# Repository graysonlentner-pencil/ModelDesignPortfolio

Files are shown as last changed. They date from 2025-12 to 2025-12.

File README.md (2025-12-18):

Model & Design Project:
Automated Snow Machine - Model & Design  |  Spring Semester, 2025.
Collaborated with a team to construct a scaled-down version of a snow machine that was able to pivot the nozzle, allowing for a wider range and thus reducing the number of machines to cover a hill. 
Developed a 3D model (Designed in OnShape) of a miniature air compressor powered by a stepper motor, as well as a pinch valve controlled by a servo motor.
Featured as a finalist in the 2025 MTU Design Expo.

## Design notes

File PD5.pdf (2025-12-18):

L36 _ 05
Megan Antczak, Clare Kowalczyk, Grayson Lentner, Noah Walters

PD5 - FMEA Memo

Executive Statement/Introduction

In this memo, we discuss the implication of FMEA, or Failure Modes and Effects Analysis, in our current project, an autonomous snowmaker. This analysis will allow us to effectively detect errors and failures in our design, and minimize them to the fullest extent possible without reducing the effectiveness or functionality of the device. This stage of development is essential for the customer, as major safety hazards and defects to the user are caught. New changes to the existing design are then made to eliminate these failures to the best of the designer’s ability.

Background

Our product is an autonomous snowmaker. The objective of our product is to improve skiing conditions for the large population of skiers, specifically in the Midwest region. Our product will autonomously detect ideal snowmaking conditions using temperature and humidity sensors and the necessity to make new snow. If a need for more snow is detected, our product will create new snow through a device with a pressurized pump with a mist nozzle. This design will evenly distribute uniform snow in hazardous areas. This innovation will greatly improve the consistency of slopes. Therefore, skiers' safety, enjoyment, and overall experience will be substantially enhanced.
This product will bring attention to the importance of maintaining ski hills for recreation and sport. In the upper peninsula last year several popular ski hills had to close very early due to the abnormal winter. With this product, the resorts could extend their season bringing more tourism and innovation to the area.

Methodology

Our procedure for the FMEA analysis is as follows:

1. Description of parts and their modes of failure - Every significant component of our system, including but not limited to the pump, nozzle, and fan is identified. Most failure modes are identified and connected to their corresponding parts.
2. Symptoms, Effects, and Significance Rating - The symptoms of failures are identified along with the possible effects and damages they may have on the customer. The symptoms and effects are then used to conjure a Significance Rating from 1 to 10 based on how severe the failure may be to the customer, with 10 being the most severe.

### 3. Probability of Occurrence Rating - Notes are produced to determine how likely

the failure mode is to occur, and then a probability rating from 1 to 10, with 10 being the most likely, is determined based on these notes.

### 4. Detectability Rating - Notes about how a failure mode may be detected before it

occurs are taken, and then are used to determine a detectability rating from 1 to 10, 10 being the least detectable.

### 5. Risk Priority Value - Risk priority values are calculated by multiplying the

significance rating, probability rating, and detectability rating together. The risk priority value is then used to determine which failure modes require the most attention.

Results and Discussion

Through our discussion of each hazard and the completion of the FMEA analysis, we identified 8 different components of our design to revise. These include the water pump, mist nozzle, tubing, DC motor/fan, servo, servo value, wiring, and temperature and humidity sensor. We went over multiple different fail mechanisms for each of the components through research into common problems as well as thinking through environmental conditions or basic human errors that might occur.

Parts, Concerns, & Solutions

### 1. Water Pump: (clogged, internal friction, not enough power/pressure supplied)

Solutions: Create a protective structure over the inlet, apply lubricant to areas of friction, and modify the stepper motor to supply greater torque.
– Average Risk Priority Number: 58.7
2. Mist Nozzle: (uneven water distribution, unsuitable mist power, clogged, freezes over, breaks from failure)
Solutions: use references for nozzle design, test design with the right pressure and environmental conditions, calibrate to apply the right amount of pressure, and use durable material and design aspects.
– Average Risk Priority Number: 162.5

### 3. Tubing: (leaks, freezes over)

Solutions: use extra adhesive or connective material (tape), and heat/insulate the water supply to keep it from freezing
– Average Risk Priority Number: 224

### 4. DC Motor / Fan: (not enough air current to propel mist)

Solutions: determine the right current and proper mist size before in a test environment
– Average Risk Priority Number: 60

### 5. Servo: (motor fails)

Solutions: intentional placement to minimize failure of moving marts – Average Risk Priority Number: 8

### 6. Servo Value: (seal is not sufficient)

Solutions: rubber material to create a seal
– Average Risk Priority Number: 80

### 7. Wiring: (not secured/comes loose, short circuits)

Solutions: if they come undone they will be detected through electronics not operating, and can be fixed manually after that, prevention includes checking all connections before the final assembly
– Average Risk Priority Number: 18

### 8. Temperature & Humidity: (correct conditions are not detected, doesn’t work)

Solutions: testing before implementation into the device.
– Average Risk Priority Number: 36

Many of the hazards resulted in unsafe conditions for users of the ski hills, thus our rating for failure severity was based on how dangerous it was to the public. In cases where the water was distributed in heavy amounts, the snow would not form in the process of the device. This would create more ice patches on the ski hills and make the slope very dangerous for any of the people using it that day. Best case scenario, the ski hill would have to close down for the day and lose profit. Other hazards resulted in the device failing to work, so those were rated less severe due to no possibility of human casualty.

We chose the mist nozzle and the tubing as our top hazards because almost all of their failure symptoms had consequences involving injury. Both also had a high chance of happening based on how likely it was that they could freeze or break under temperature-induced brittleness. For the mist nozzle we decided to test our 3D printed nozzle before implementation into the design as well as testing it in cold conditions to test whether it would freeze over or fracture. For the tubing, we discussed implementing an insulation system or water heater to keep the water supply from freezing. We also discussed adding extra reinforcement to the joints of the tubing to reduce fractures and leaks.

These changes will reduce the occurrences of such failures and keep extra water from being distributed over the hill. This will result in safer ski hill conditions overall and reduce the impact of such failures on the community.

Conclusion

We have considered many failure modes in our device including frozen water in tubing to reduce hazards that may be brought about by the device. These failure modes were detected via FMEA and included but were not limited to the uneven distribution of water, and torque failures within the motors of the device. Several precautions have been taken to minimize these failures as well as their effects, ensuring the customer will be satisfied with their use of the device. These Precautions include installing insulation within certain parts of the device to prevent freezing, as well as modifying some motors to withstand a higher amount of torque. In total, significant errors and failures of the device are being taken into account and will be minimized in the interest of the user.

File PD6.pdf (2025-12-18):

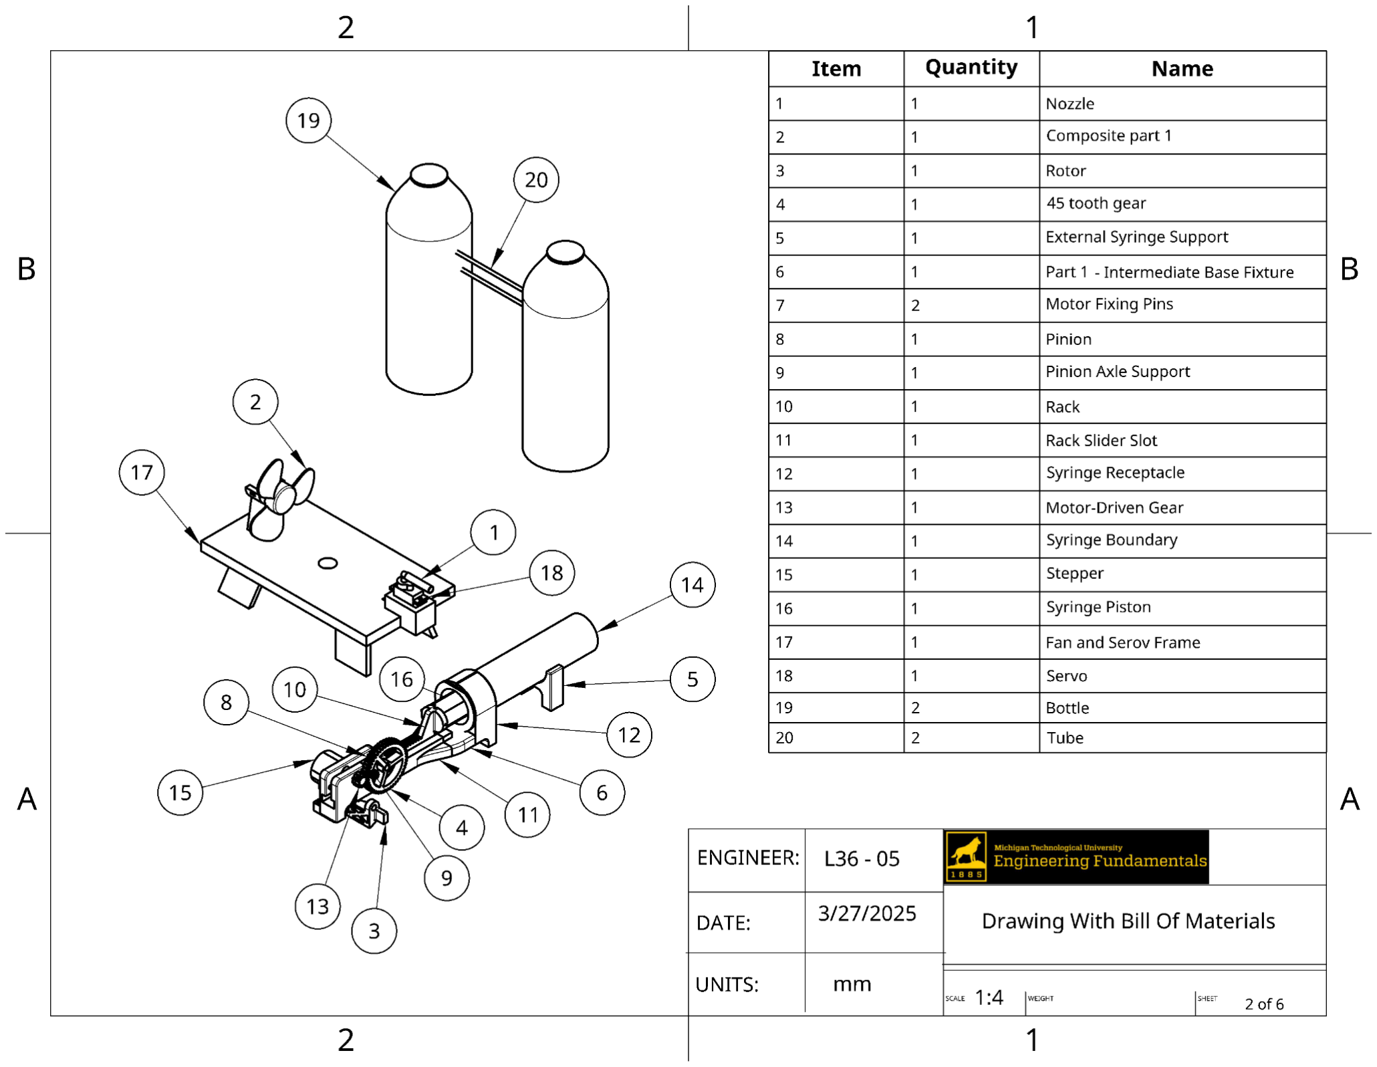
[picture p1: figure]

Introduction

For our project, we are designing an autonomous snow machine. The desired intent of our machine is to create more ideal skiing conditions, as well as make the jobs of the workers easier by not making them scale the ski hill to adjust the machine. The 3D model will play a significant role in helping us visualize what we want our machine to look like when it is fully built. It also allows us to create each individual part to the scale that we need them to be, making it possible to 3D print them.

Progress

Over the weekend, we assigned each team member to design on Onshape some of the different parts that need to be 3D printed. We have each made progress on our assigned parts and some parts have been completed, while others still have a little bit left to do. Grayson has taken the task of creating our pump, which is the most complex and intricate piece we will be 3D printing. Megan has completed the frame for the micro servo and the DC motor. Clare has completed the mist nozzle. Noah made the fan. Everyone has taken responsibility for different complex parts and has excelled. Overall, we are still deciding who needs to do some of the other minor parts on OnShape but we are rather close to being able to print everything.

Challenges

Our team encountered many challenges in the modeling and drawing process. A big struggle was communication after we divided up all the parts. Each person had to work individually but there were still strict guidelines and restrictions that needed to be followed to ensure that our device would run smoothly. Our team had to maintain very effective communication to execute unity for this assembly. Some forms of this communication included drawings on whiteboards, comments on parts, and repeating dimensions multiple times.
It was also challenging to finalize the design of this model. Up until this point, our project was very conceptual and did not have a concrete vision. This project deliverable forced us to begin to bring our ideas to life. Some of the drafting did not go very smoothly but as a team, we worked it out ensuring everyone’s ideas were heard and accounted for. The difficulties and challenges we faced were beneficial and necessary for the production of this project.

Next Steps

The next step of our project includes going to the Fab Lab. Here, we will 3D print many aspects of our project. Such parts include the nozzle, the fan and servo frame, fan blades, and many parts for the pump. After completion of the 3D printing we will thoroughly inspect products to make sure they are up to par and redesign and reprint as needed. After the perfection of our parts, we will put our assembly together. With our project all put together, testing will commence to find any possible flaws with our design. As seen in our FMEA table, each part has its own major or minor potential breaking points. After we have worked out all the flaws, we will have a working machine ready for the final test.

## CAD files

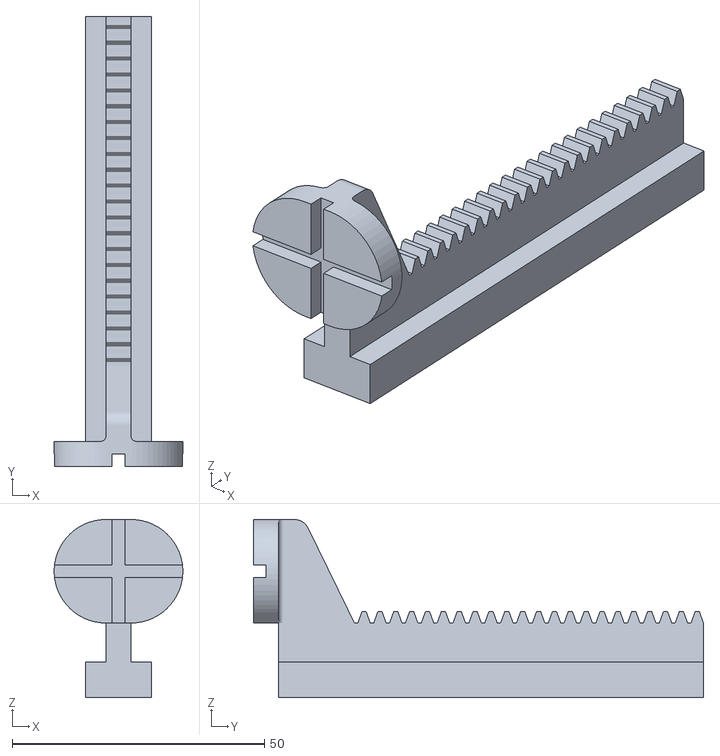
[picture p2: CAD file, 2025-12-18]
Rack.stl
25.5 x 89.1 x 35.2

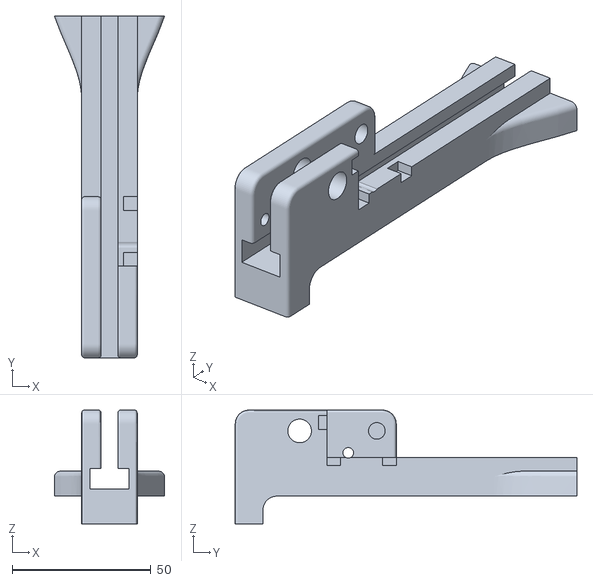
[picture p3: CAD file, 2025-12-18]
Rack slider slot.stl
39.6 x 123.0 x 41.0

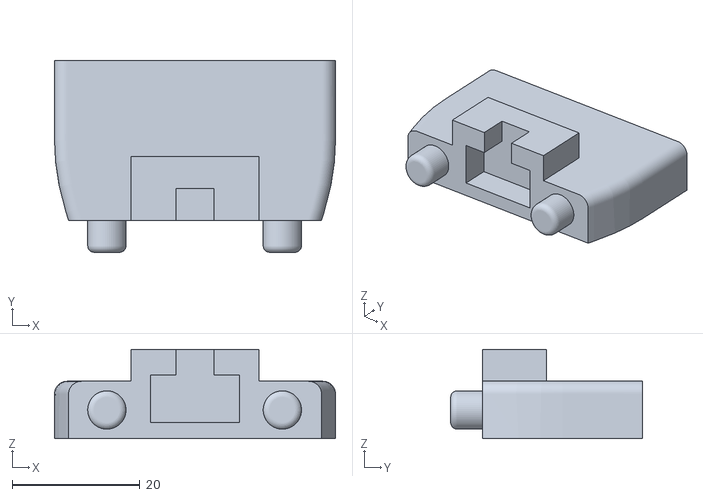
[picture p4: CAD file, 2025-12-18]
Intermediate Base Fixture.stl
44.0 x 30.0 x 14.0

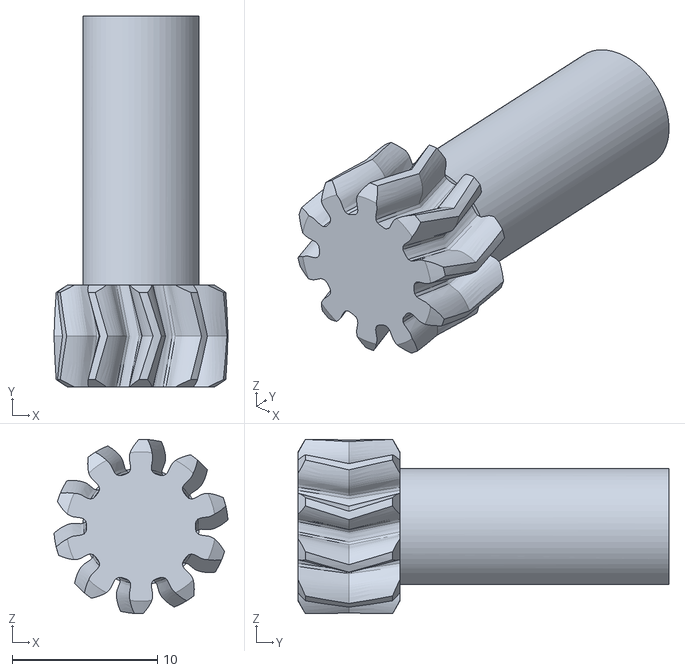
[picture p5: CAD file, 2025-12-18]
Motor-Driven Gear - Motor-Driven Gear.stl
12.0 x 25.5 x 12.0

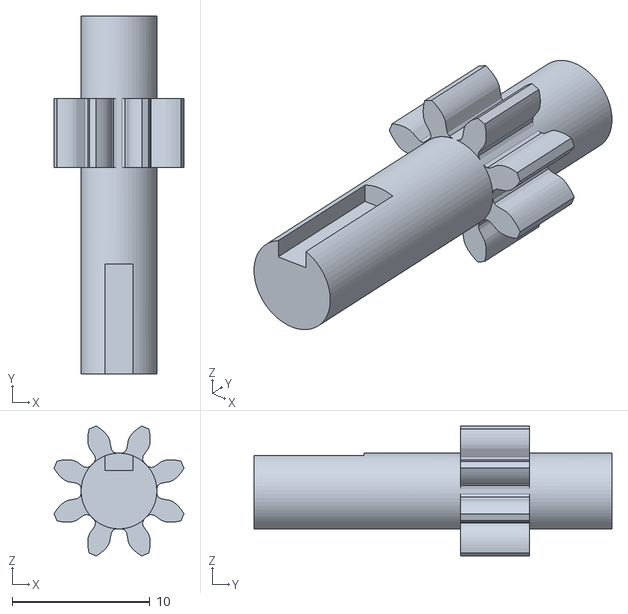
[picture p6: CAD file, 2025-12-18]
Pinion.stl
9.43 x 26.0 x 9.43

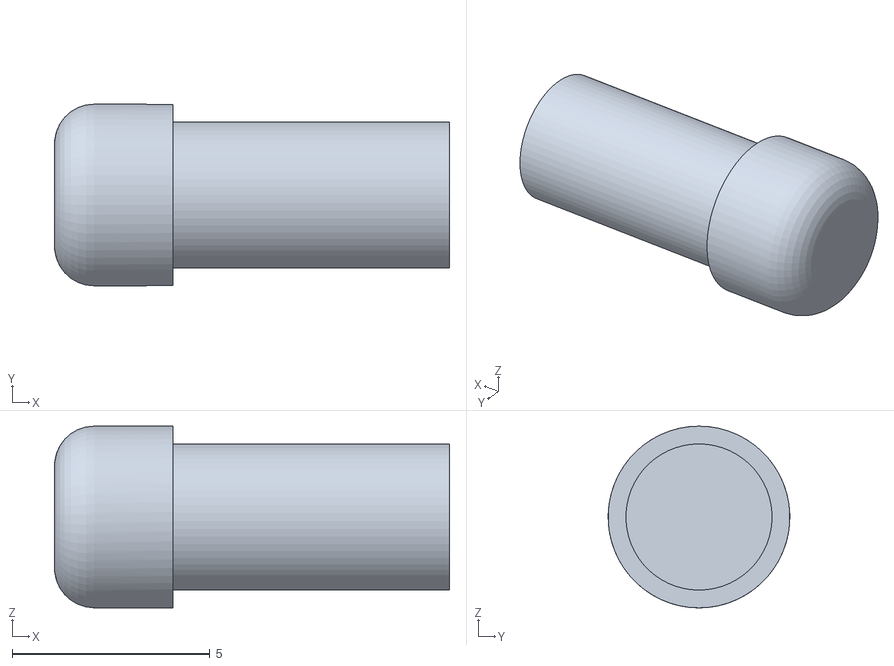
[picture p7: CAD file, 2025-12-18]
Motor fixing pins.stl
10.0 x 4.60 x 4.60

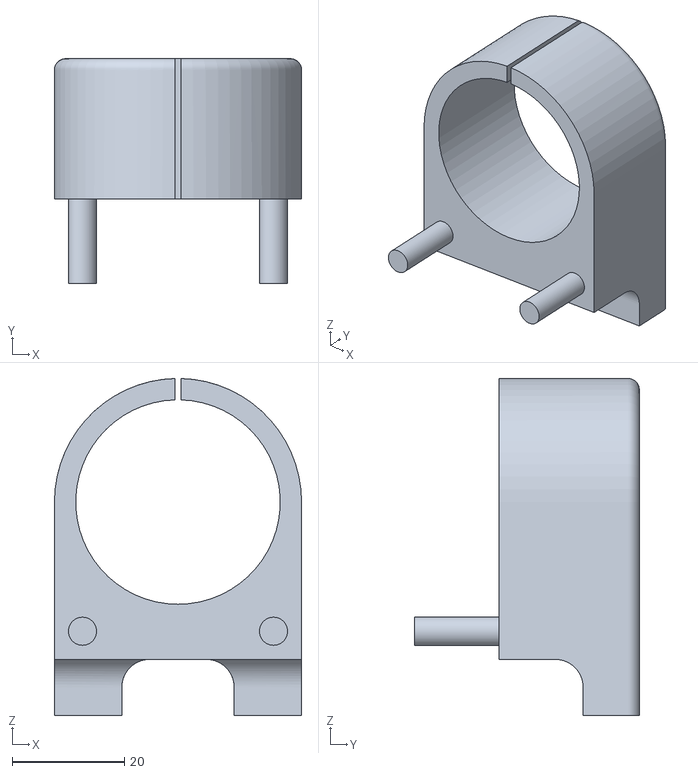
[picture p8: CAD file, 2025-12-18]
Syrnge receptacle.stl
44.0 x 40.0 x 60.0

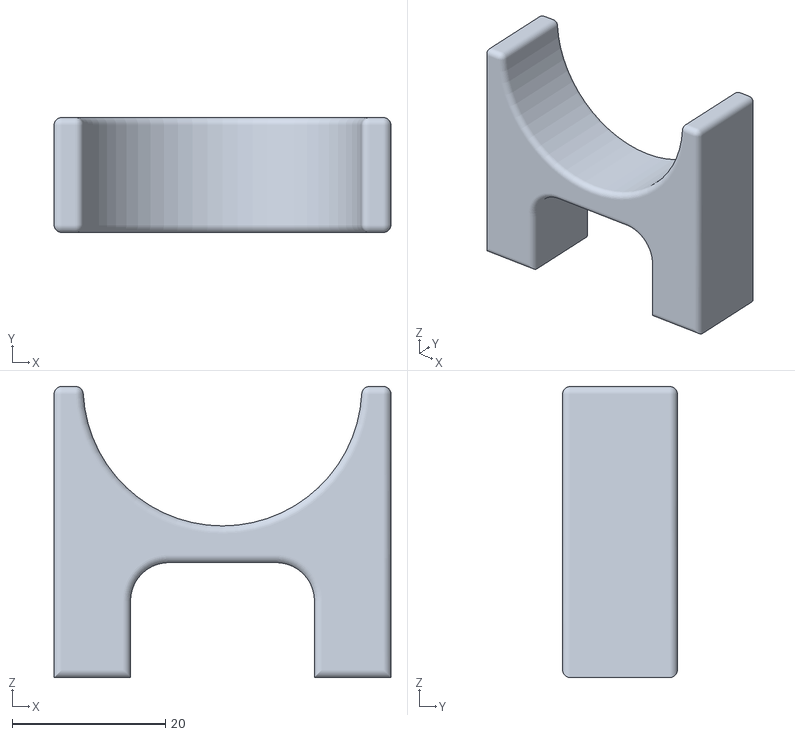
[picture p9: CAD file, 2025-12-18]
External Syringe Support.stl
44.0 x 15.0 x 38.0

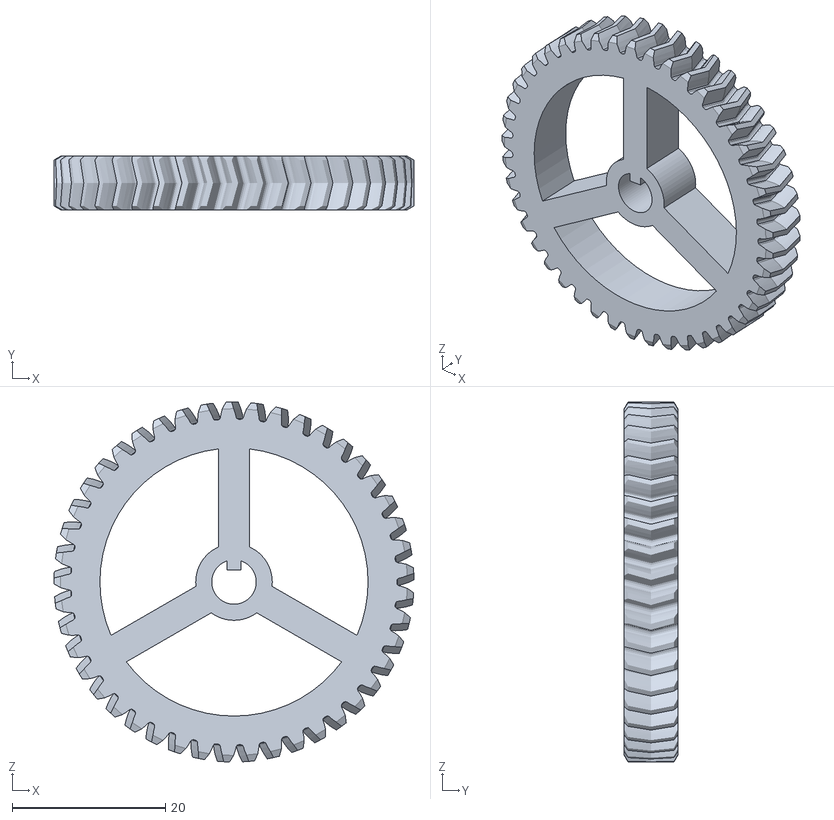
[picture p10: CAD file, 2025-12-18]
45 Tooth Gear.stl
47.0 x 7.00 x 47.0

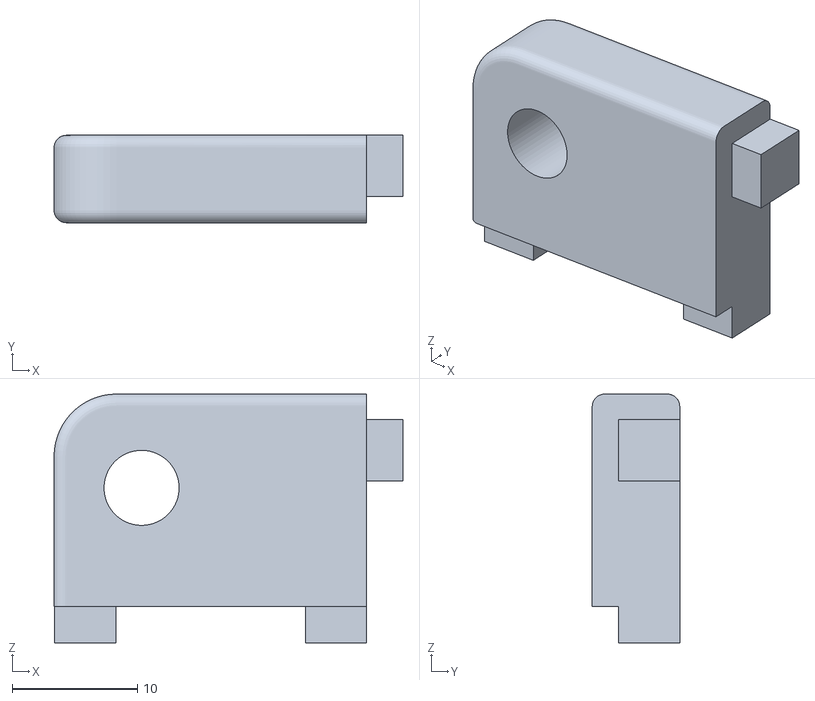
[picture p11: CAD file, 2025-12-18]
Pinion Axle Support.stl
27.9 x 7.00 x 19.9
